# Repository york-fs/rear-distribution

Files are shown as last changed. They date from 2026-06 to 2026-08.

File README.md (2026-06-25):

# Rear Distribution Board







The rear distribution board is the central board of the LVS. It provides fusing for all other LVS components and
interfaces with the front, TSAC, and TS box distribution boards, as well as the inverter via AMPSEAL connections.

[Latest Release](https://github.com/york-fs/rear-distribution/releases/latest)
[Interactive BOM](https://york-fs.github.io/rear-distribution/ibom.html)

## Features

* **Blade Fuse Holders for All Other LVS components**
* **Fused 12 V and Shutdown Monitoring**
* **On-board microSD Slot**
* **UART Output for Radio Communication**

Render Preview

## Cloning

A recursive clone must be used to download the `kicad-library` repository:

    git clone --recursive https://github.com/york-fs/rear-distribution.git

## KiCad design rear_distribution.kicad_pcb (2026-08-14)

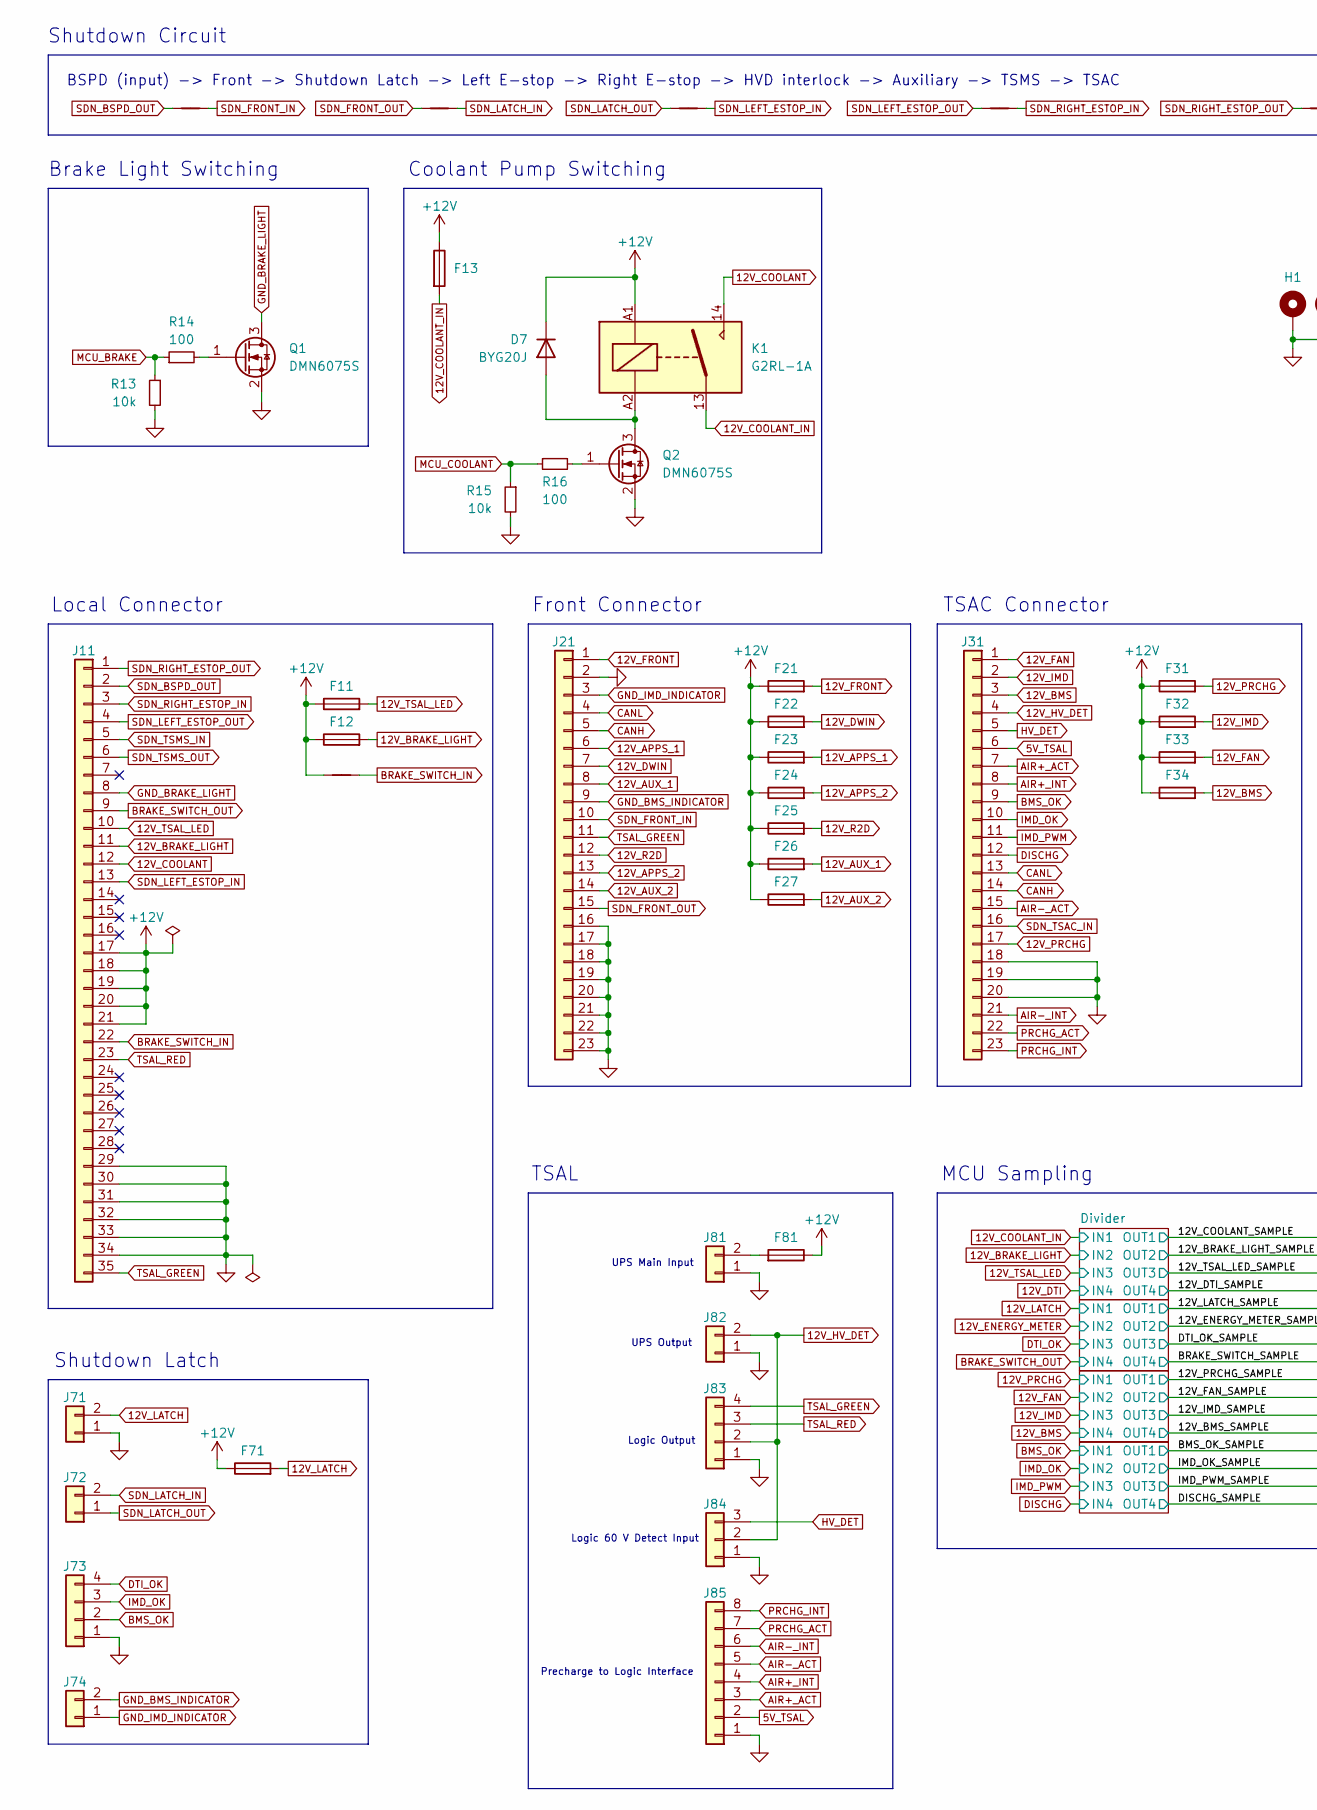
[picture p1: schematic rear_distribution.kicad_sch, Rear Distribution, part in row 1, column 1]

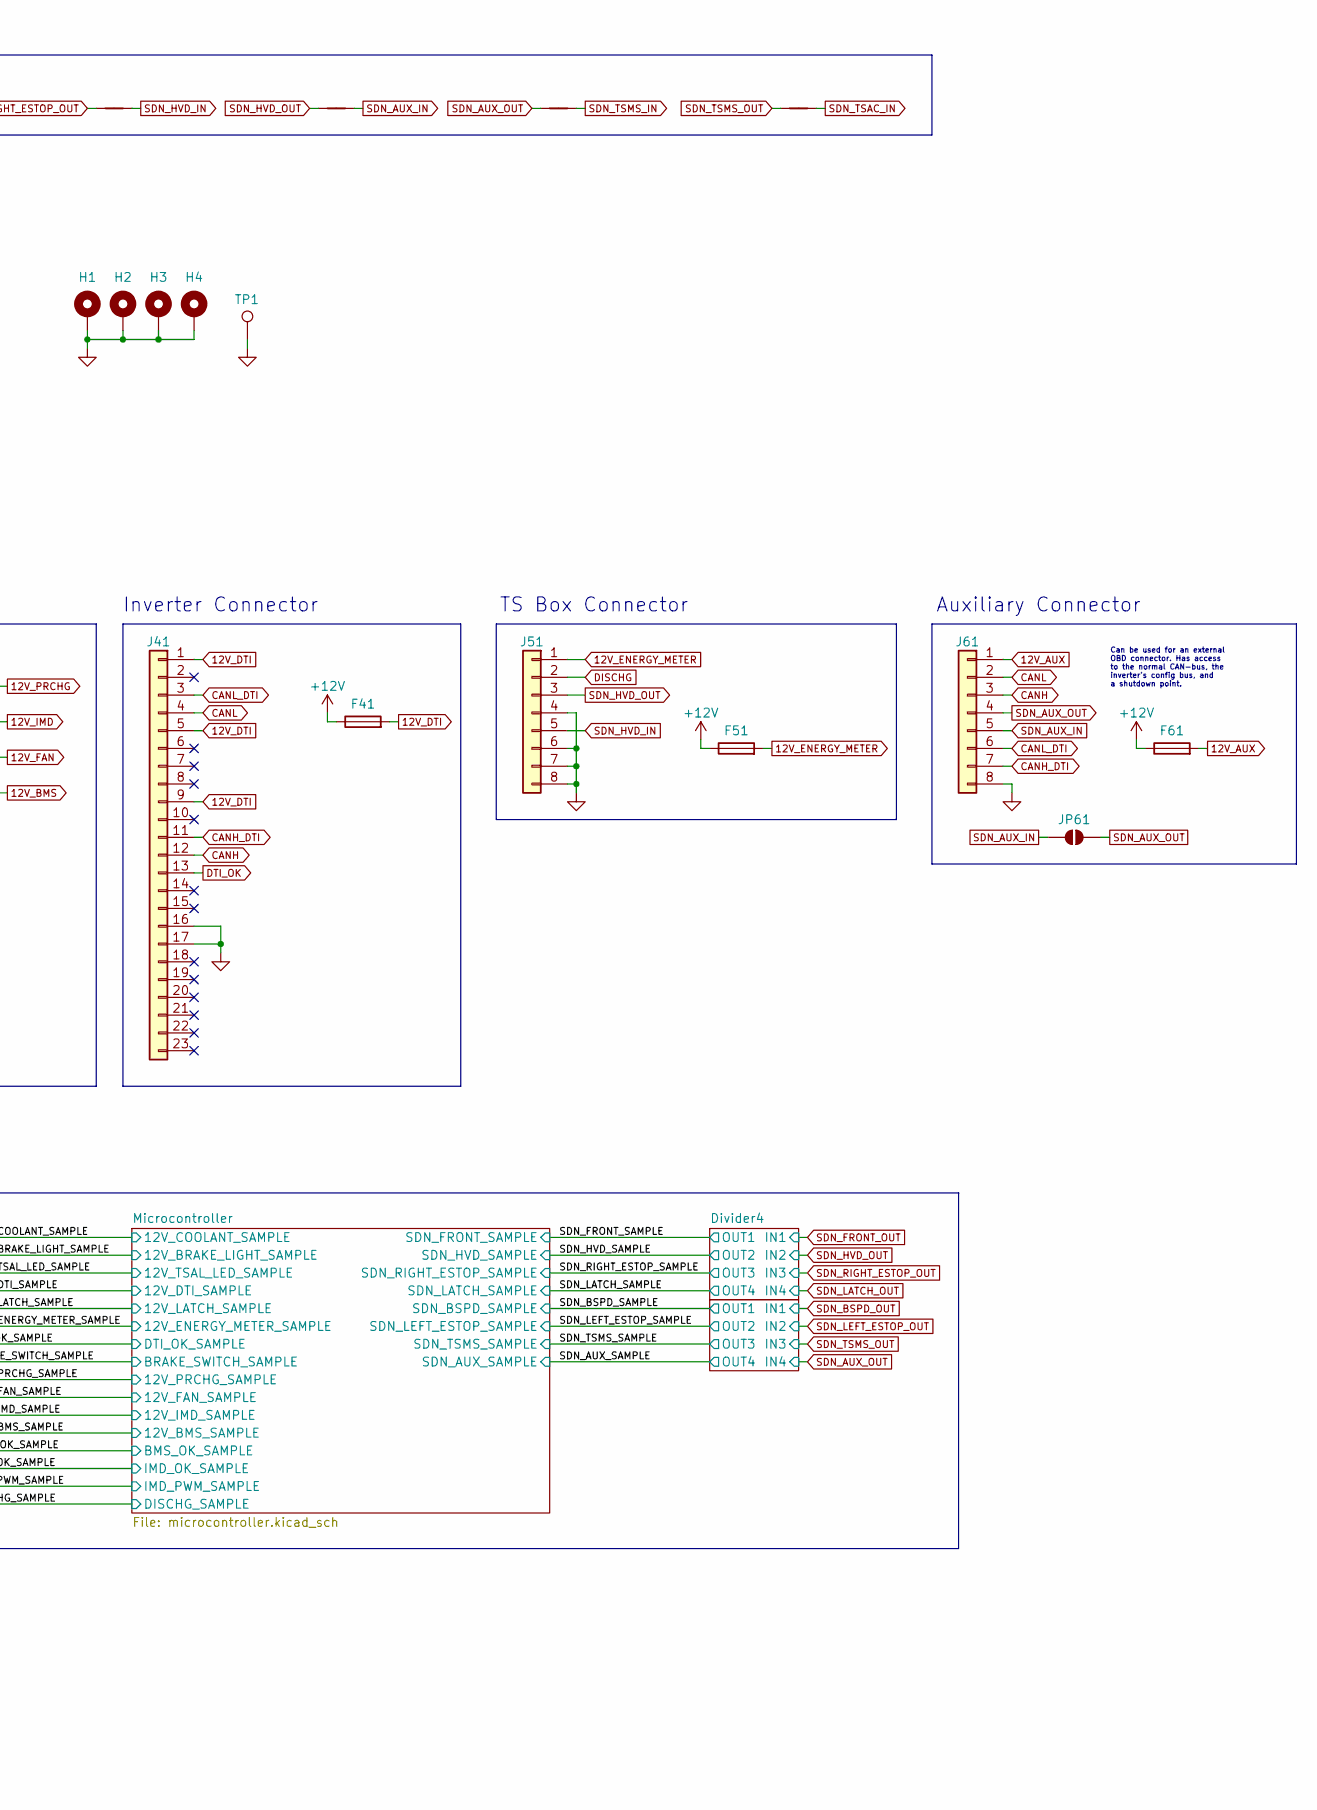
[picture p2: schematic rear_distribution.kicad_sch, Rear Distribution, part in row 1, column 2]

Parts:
D7: BYG20J; D_SMA; Mfr # BYG20J-E3/TR; DigiKey # BYG20J-E3/TR3GICT-ND
F11, F12, F13, F21, F22, F23, F24, F25, F26, F27, F31, F32, F33, F34, F41, F51, F61, F71, F81: Fuse; Keystone_3557-2; Mfr # 3557-2; DigiKey # 36-3557-2-ND
H1, H2, H3, H4: MountingHole_Pad; MountingHole_3.2mm_M3_Pad_Via
J11: Conn_01x35; AMPSEAL-35-776163; Mfr # 776163-1; DigiKey # A106460-ND
J21, J31, J41: Conn_01x23; AMPSEAL-23-776087; Mfr # 776087-1; DigiKey # A107007-ND
J51, J61: Conn_01x08; AMPSEAL-8-776280; Mfr # 776280-1; DigiKey # 776280-1-ND
J71, J81: Conn_01x02; MolexMicrofitPlus1x2; Mfr # 2157601022; DigiKey # 900-2157601022-ND
J72: Conn_01x02; MolexMicrofitPlus1x2; Mfr # 2157601032; DigiKey # 900-2157601032-ND
J73, J83: Conn_01x04; MolexMicrofitPlus1x4; Mfr # 2157601004; DigiKey # 900-2157601004-ND
J74, J82: Conn_01x02; MolexMicrofitPlus1x2; Mfr # 2157601002; DigiKey # 900-2157601002-ND
J84: Conn_01x03; MolexMicrofitPlus1x3; Mfr # 2157601003; DigiKey # 900-2157601003-ND
J85: Conn_01x08; MolexMicrofitPlus1x8; Mfr # 2157601008; DigiKey # 900-2157601008-ND
JP61: SolderJumper_2_Open; SolderJumper-2_P1.3mm_Open_RoundedPad1.0x1.5mm
K1: G2RL-1A; Relay_SPST_Omron_G2RL-1A; Mfr # G2RL-1A-DC12; DigiKey # Z140-ND
NT2, NT3, NT4, NT5, NT6, NT7, NT8, NT9, NT10: NetTie_2; NetTie-2_SMD_Pad0.5mm
Q1, Q2: DMN6075S; SOT-23; Mfr # DMN6075S-7; DigiKey # DMN6075S-7DICT-ND
R13, R15: 10k; R_0603_1608Metric; Mfr # 0603WAF1002T5E; LCSC # C25804
R14, R16: 100; R_0603_1608Metric
TP1: TestPoint; TestPoint_Keystone_5019_Miniature; Mouser # 534-5019; DigiKey # 36-5019CT-ND

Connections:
5V_TSAL: J31.6, J85.2
12V_APPS_1: F23.2, J21.6
12V_APPS_2: F24.2, J21.13
12V_AUX: F61.2, J61.1
12V_AUX_1: F26.2, J21.8
12V_AUX_2: F27.2, J21.14
12V_BMS: F34.2, J31.3; also elsewhere on the board
12V_BRAKE_LIGHT: F12.2, J11.11; also elsewhere on the board
12V_COOLANT: J11.12, K1.14
12V_COOLANT_IN: F13.2, K1.13; also elsewhere on the board
12V_DTI: F41.2, J41.1, J41.5, J41.9; also elsewhere on the board
12V_DWIN: F22.2, J21.7
12V_ENERGY_METER: F51.2, J51.1; also elsewhere on the board
12V_FAN: F33.2, J31.1; also elsewhere on the board
12V_FRONT: F21.2, J21.1
12V_HV_DET: J31.4, J82.2, J83.2, J84.2
12V_IMD: F32.2, J31.2; also elsewhere on the board
12V_LATCH: F71.2, J71.2; also elsewhere on the board
12V_PRCHG: F31.2, J31.17; also elsewhere on the board
12V_R2D: F25.2, J21.12
12V_TSAL_LED: F11.2, J11.10; also elsewhere on the board
+12V: D7.1 (K), F11.1, F12.1, F13.1, F21.1, F22.1, F23.1, F24.1, F25.1, F26.1, F27.1, F31.1, F32.1, F33.1, F34.1, F41.1, F51.1, F61.1, F71.1, F81.1, J11.17, J11.18, J11.19, J11.20, J11.21, K1.A1, NT2.1; also elsewhere on the board
AIR+_ACT: J31.7, J85.3
AIR+_INT: J31.8, J85.4
AIR-_ACT: J31.15, J85.5
AIR-_INT: J31.21, J85.6
BMS_OK: J31.9, J73.2; also elsewhere on the board
BRAKE_SWITCH_IN: J11.22, NT2.2
BRAKE_SWITCH_OUT: J11.9; also elsewhere on the board
CANH: J21.5, J31.14, J41.12, J61.3; also elsewhere on the board
CANH_DTI: J41.11, J61.7
CANL: J21.4, J31.13, J41.4, J61.2; also elsewhere on the board
CANL_DTI: J41.3, J61.6
DISCHG: J31.12, J51.2; also elsewhere on the board
DTI_OK: J41.13, J73.4; also elsewhere on the board
GND: H1.1, H2.1, H3.1, H4.1, J11.29, J11.30, J11.31, J11.32, J11.33, J11.34, J21.2, J21.16, J21.17, J21.18, J21.19, J21.20, J21.21, J21.22, J21.23, J31.18, J31.19, J31.20, J41.16, J41.17, J51.4, J51.6, J51.7, J51.8, J61.8, J71.1, J73.1, J81.1, J82.1, J83.1, J84.1, J85.1, Q1.2 (S), Q2.2 (S), R13.2, R15.2, TP1.1; also elsewhere on the board
GND_BMS_INDICATOR: J21.9, J74.2
GND_BRAKE_LIGHT: J11.8, Q1.3 (D)
GND_IMD_INDICATOR: J21.3, J74.1
HV_DET: J31.5, J84.3
IMD_OK: J31.10, J73.3; also elsewhere on the board
IMD_PWM: J31.11; also elsewhere on the board
MCU_BRAKE: R13.1, R14.1; also elsewhere on the board
MCU_COOLANT: R15.1, R16.1; also elsewhere on the board
unnamed: D7.2 (A), K1.A2, Q2.3 (D)
unnamed: F81.2, J81.2
unnamed: Q1.1 (G), R14.2
unnamed: Q2.1 (G), R16.2
PRCHG_ACT: J31.22, J85.7
PRCHG_INT: J31.23, J85.8
SDN_AUX_IN: J61.5, JP61.1 (A), NT8.2
SDN_AUX_OUT: J61.4, JP61.2 (B), NT9.1; also elsewhere on the board
SDN_BSPD_OUT: J11.2, NT3.1; also elsewhere on the board
SDN_FRONT_IN: J21.10, NT3.2
SDN_FRONT_OUT: J21.15, NT4.1; also elsewhere on the board
SDN_HVD_IN: J51.5, NT7.2
SDN_HVD_OUT: J51.3, NT8.1; also elsewhere on the board
SDN_LATCH_IN: J72.2, NT4.2
SDN_LATCH_OUT: J72.1, NT5.1; also elsewhere on the board
SDN_LEFT_ESTOP_IN: J11.13, NT5.2
SDN_LEFT_ESTOP_OUT: J11.4, NT6.1; also elsewhere on the board
SDN_RIGHT_ESTOP_IN: J11.3, NT6.2
SDN_RIGHT_ESTOP_OUT: J11.1, NT7.1; also elsewhere on the board
SDN_TSAC_IN: J31.16, NT10.2
SDN_TSMS_IN: J11.5, NT9.2
SDN_TSMS_OUT: J11.6, NT10.1; also elsewhere on the board
TSAL_GREEN: J11.35, J21.11, J83.4
TSAL_RED: J11.23, J83.3

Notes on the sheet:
TSAL
Logic Output
UPS Main Input
Inverter Connector
UPS Output
Logic 60 V Detect Input
Auxiliary Connector
TSAC Connector
Local Connector
Precharge to Logic Interface
MCU Sampling
Can be used for an external OBD connector. Has access to the normal CAN-bus, the inverter's config bus, and a shutdown point.
Front Connector
BSPD (input) -> Front -> Shutdown Latch -> Left E-stop -> Right E-stop -> HVD interlock -> Auxiliary -> TSMS -> TSAC
Brake Light Switching
Shutdown Latch
Shutdown Circuit
Coolant Pump Switching
TS Box Connector

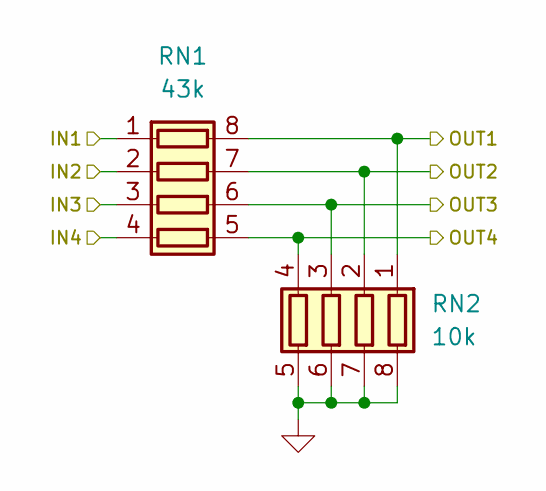
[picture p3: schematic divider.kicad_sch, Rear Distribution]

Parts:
RN1: 43k; R_Array_Convex_4x1206; Mfr # YC324-JK-0747KL; DigiKey # 13-YC324-JK-0747KLCT-ND
RN2: 10k; R_Array_Convex_4x1206; Mfr # YC324-FK-0710KL; DigiKey # 13-YC324-FK-0710KLCT-ND

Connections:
12V_BRAKE_LIGHT: RN1.2 (R2.1); also elsewhere on the board
12V_COOLANT_IN: RN1.1 (R1.1); also elsewhere on the board
12V_DTI: RN1.4 (R4.1); also elsewhere on the board
12V_TSAL_LED: RN1.3 (R3.1); also elsewhere on the board
/12V_BRAKE_LIGHT_SAMPLE: RN1.7 (R2.2), RN2.2 (R2.1); also elsewhere on the board
/12V_COOLANT_SAMPLE: RN1.8 (R1.2), RN2.1 (R1.1); also elsewhere on the board
/12V_DTI_SAMPLE: RN1.5 (R4.2), RN2.4 (R4.1); also elsewhere on the board
/12V_TSAL_LED_SAMPLE: RN1.6 (R3.2), RN2.3 (R3.1); also elsewhere on the board
GND: RN2.5 (R4.2), RN2.6 (R3.2), RN2.7 (R2.2), RN2.8 (R1.2); also elsewhere on the board

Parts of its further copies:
RN3, RN5, RN7, RN9, RN11: 43k; R_Array_Convex_4x1206; Mfr # YC324-JK-0747KL; DigiKey # 13-YC324-JK-0747KLCT-ND
RN4, RN6, RN8, RN10, RN12: 10k; R_Array_Convex_4x1206; Mfr # YC324-FK-0710KL; DigiKey # 13-YC324-FK-0710KLCT-ND

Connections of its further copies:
12V_BMS: RN5.4 (R4.1); also elsewhere on the board
12V_ENERGY_METER: RN3.2 (R2.1); also elsewhere on the board
12V_FAN: RN5.2 (R2.1); also elsewhere on the board
12V_IMD: RN5.3 (R3.1); also elsewhere on the board
12V_LATCH: RN3.1 (R1.1); also elsewhere on the board
12V_PRCHG: RN5.1 (R1.1); also elsewhere on the board
/12V_BMS_SAMPLE: RN5.5 (R4.2), RN6.4 (R4.1); also elsewhere on the board
/12V_ENERGY_METER_SAMPLE: RN3.7 (R2.2), RN4.2 (R2.1); also elsewhere on the board
/12V_FAN_SAMPLE: RN5.7 (R2.2), RN6.2 (R2.1); also elsewhere on the board
/12V_IMD_SAMPLE: RN5.6 (R3.2), RN6.3 (R3.1); also elsewhere on the board
/12V_LATCH_SAMPLE: RN3.8 (R1.2), RN4.1 (R1.1); also elsewhere on the board
/12V_PRCHG_SAMPLE: RN5.8 (R1.2), RN6.1 (R1.1); also elsewhere on the board
/BMS_OK_SAMPLE: RN7.8 (R1.2), RN8.1 (R1.1); also elsewhere on the board
/BRAKE_SWITCH_SAMPLE: RN3.5 (R4.2), RN4.4 (R4.1); also elsewhere on the board
/DISCHG_SAMPLE: RN7.5 (R4.2), RN8.4 (R4.1); also elsewhere on the board
/DTI_OK_SAMPLE: RN3.6 (R3.2), RN4.3 (R3.1); also elsewhere on the board
/IMD_OK_SAMPLE: RN7.7 (R2.2), RN8.2 (R2.1); also elsewhere on the board
/IMD_PWM_SAMPLE: RN7.6 (R3.2), RN8.3 (R3.1); also elsewhere on the board
/SDN_AUX_SAMPLE: RN11.5 (R4.2), RN12.4 (R4.1); also elsewhere on the board
/SDN_BSPD_SAMPLE: RN11.8 (R1.2), RN12.1 (R1.1); also elsewhere on the board
/SDN_FRONT_SAMPLE: RN9.8 (R1.2), RN10.1 (R1.1); also elsewhere on the board
/SDN_HVD_SAMPLE: RN9.7 (R2.2), RN10.2 (R2.1); also elsewhere on the board
/SDN_LATCH_SAMPLE: RN9.5 (R4.2), RN10.4 (R4.1); also elsewhere on the board
/SDN_LEFT_ESTOP_SAMPLE: RN11.7 (R2.2), RN12.2 (R2.1); also elsewhere on the board
/SDN_RIGHT_ESTOP_SAMPLE: RN9.6 (R3.2), RN10.3 (R3.1); also elsewhere on the board
/SDN_TSMS_SAMPLE: RN11.6 (R3.2), RN12.3 (R3.1); also elsewhere on the board
BMS_OK: RN7.1 (R1.1); also elsewhere on the board
BRAKE_SWITCH_OUT: RN3.4 (R4.1); also elsewhere on the board
DISCHG: RN7.4 (R4.1); also elsewhere on the board
DTI_OK: RN3.3 (R3.1); also elsewhere on the board
GND: RN4.5 (R4.2), RN4.6 (R3.2), RN4.7 (R2.2), RN4.8 (R1.2), RN6.5 (R4.2), RN6.6 (R3.2), RN6.7 (R2.2), RN6.8 (R1.2), RN8.5 (R4.2), RN8.6 (R3.2), RN8.7 (R2.2), RN8.8 (R1.2), RN10.5 (R4.2), RN10.6 (R3.2), RN10.7 (R2.2), RN10.8 (R1.2), RN12.5 (R4.2), RN12.6 (R3.2), RN12.7 (R2.2), RN12.8 (R1.2); also elsewhere on the board
IMD_OK: RN7.2 (R2.1); also elsewhere on the board
IMD_PWM: RN7.3 (R3.1); also elsewhere on the board
SDN_AUX_OUT: RN11.4 (R4.1); also elsewhere on the board
SDN_BSPD_OUT: RN11.1 (R1.1); also elsewhere on the board
SDN_FRONT_OUT: RN9.1 (R1.1); also elsewhere on the board
SDN_HVD_OUT: RN9.2 (R2.1); also elsewhere on the board
SDN_LATCH_OUT: RN9.4 (R4.1); also elsewhere on the board
SDN_LEFT_ESTOP_OUT: RN11.2 (R2.1); also elsewhere on the board
SDN_RIGHT_ESTOP_OUT: RN9.3 (R3.1); also elsewhere on the board
SDN_TSMS_OUT: RN11.3 (R3.1); also elsewhere on the board

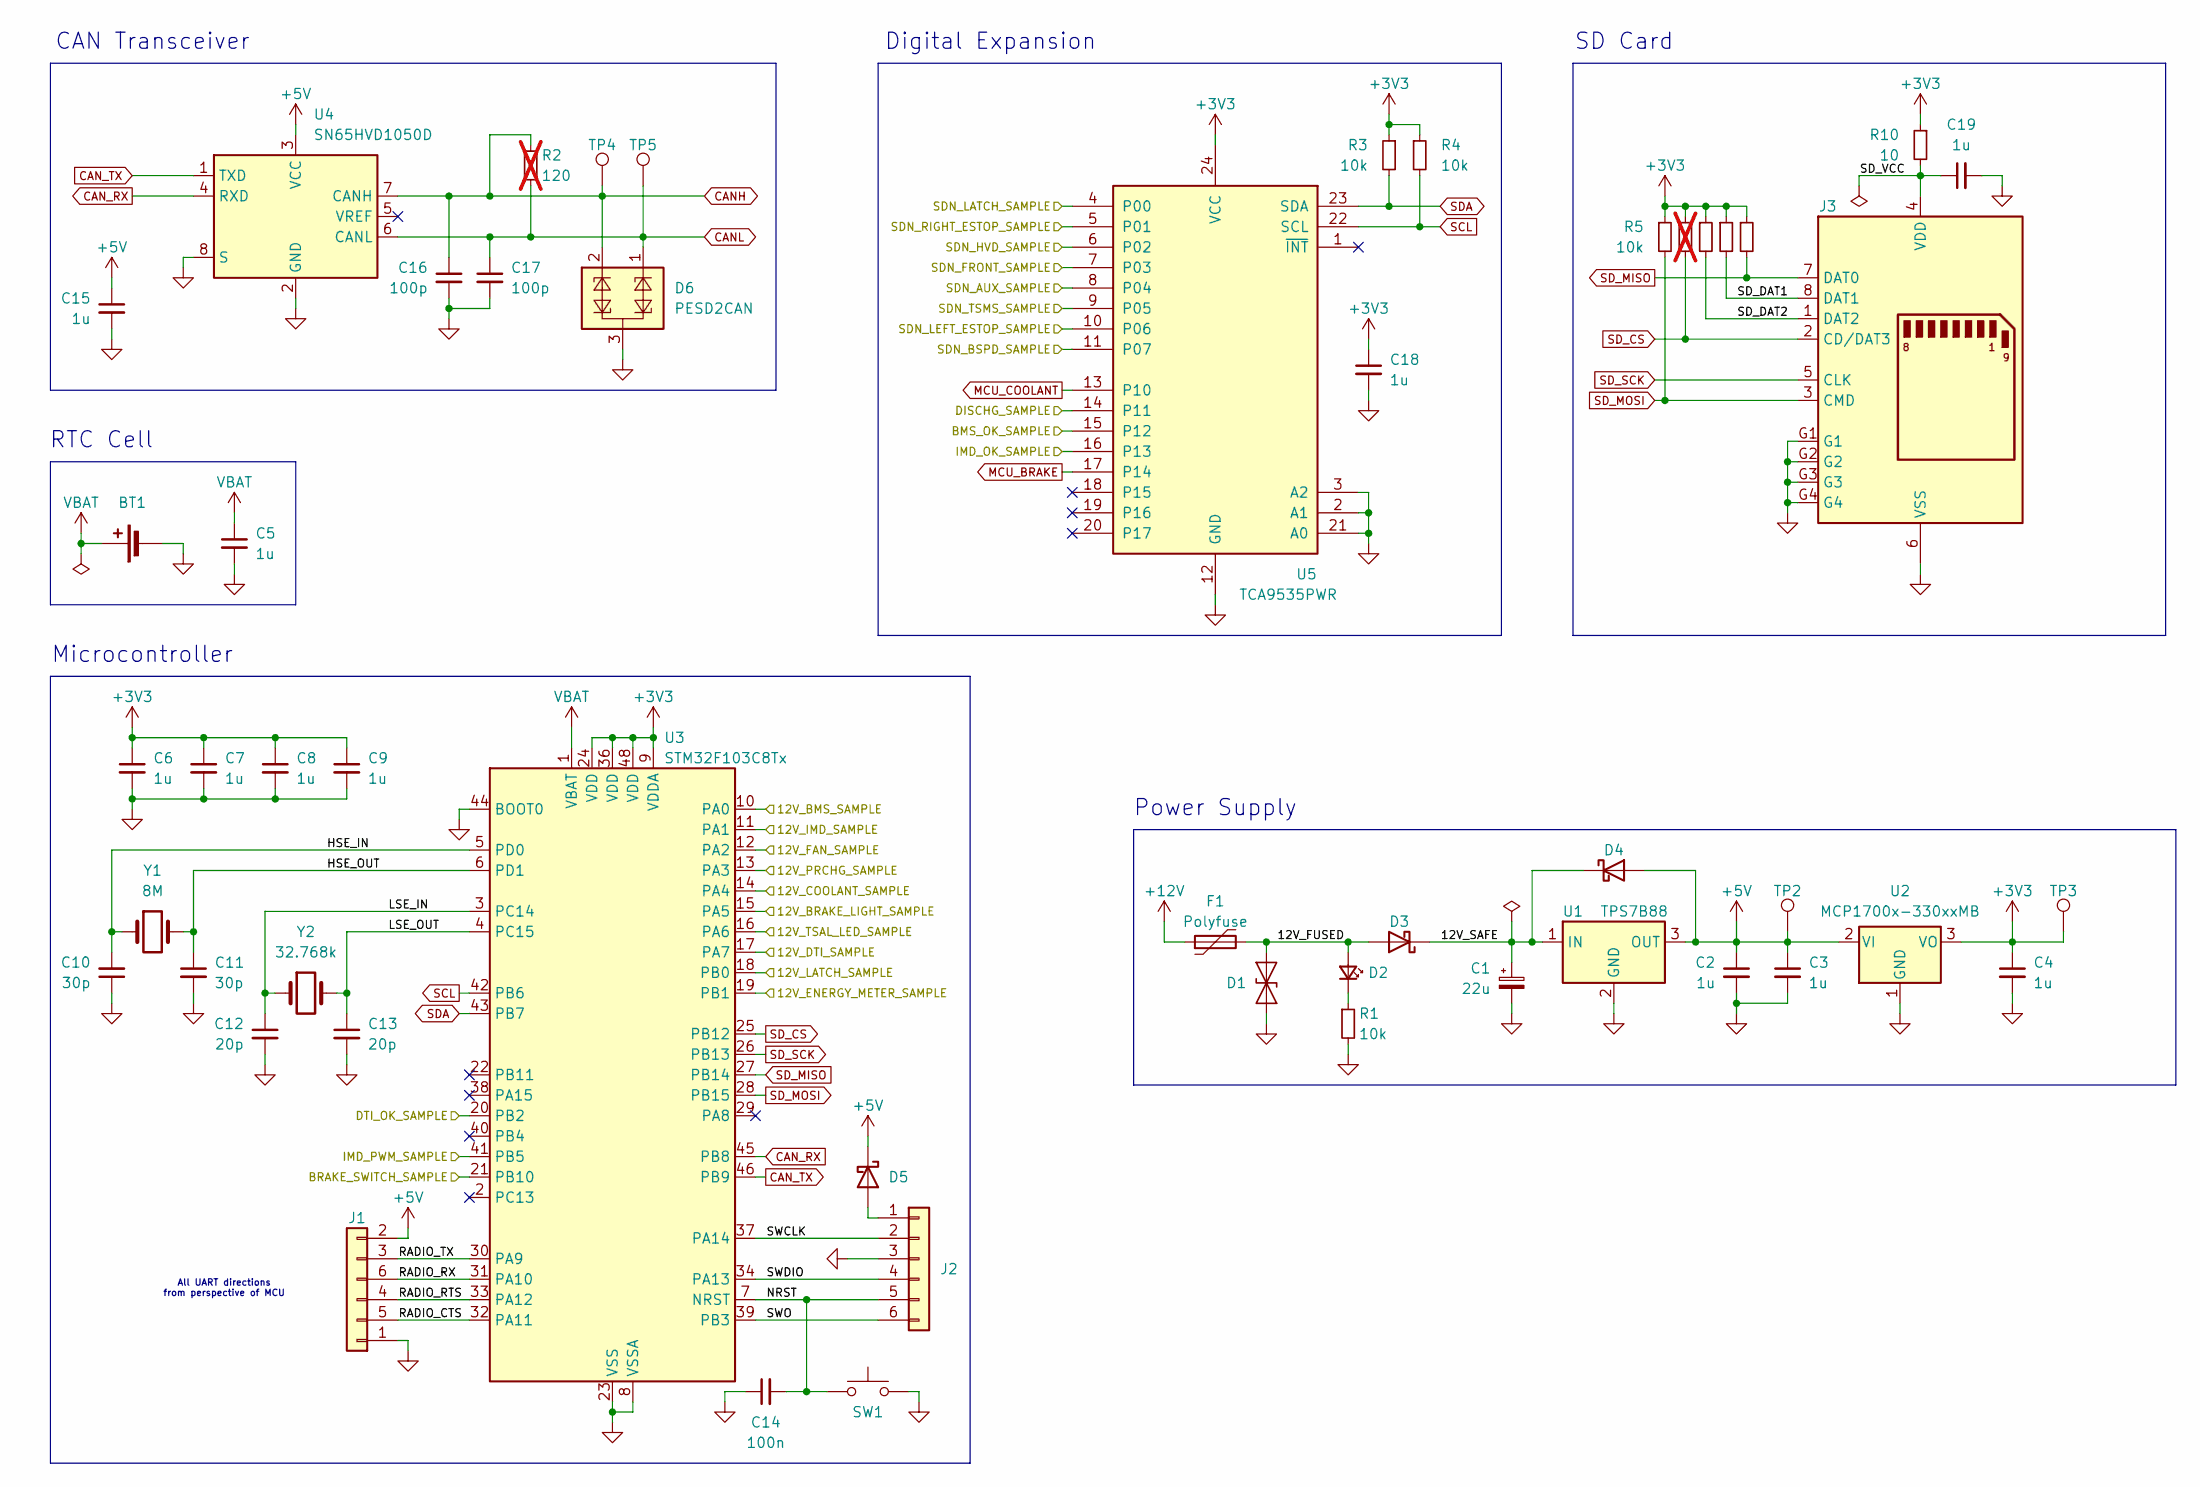
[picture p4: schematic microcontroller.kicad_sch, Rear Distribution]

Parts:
BT1: Battery_Cell; BAT-SMD_BS-CR2032-8
C1: 22u; CP_Elec_6.3x7.7; Mfr # EEEFK1J220XP; DigiKey # PCE3821CT-ND
C2, C3, C4, C5, C6, C7, C8, C9, C15, C18, C19: 1u; C_0603_1608Metric; Mfr # CL10B105KB8NQNC; LCSC # C5199872
C10, C11: 30p; C_0603_1608Metric; Mfr # GQM1875C2E300GB12D; DigiKey # 490-GQM1875C2E300GB12DCT-ND
C12, C13: 20p; C_0603_1608Metric
C14: 100n; C_0603_1608Metric; Mfr # CL10B104KB8NNNC; DigiKey # 1276-1000-1-ND
C16, C17: 100p; C_0603_1608Metric; Mfr # GCM1885C2A101JA16D; DigiKey # 490-4771-1-ND
D1: SMAJ24CA; D_SMA; Mfr # SMAJ24CA; DigiKey # SMAJ24CALFCT-ND
D2: LED_Small; LED_0603_1608Metric; Mfr # NCD0603R1; LCSC # C84263
D3, D4, D5: D_Schottky; D_SOD-323; Mfr # NSR0530H; DigiKey # NSR0530HT1GOSCT-ND
D6: PESD2CAN; SOT-23; Mfr # PESD2CAN,215; DigiKey # 1727-3891-1-ND
F1: Polyfuse; C_0805_2012Metric; Mfr # 0805L010/24YR; DigiKey # F11311CT-ND
J1: Conn_01x06; MolexMicrofitPlus2x3; Mfr # 2125280600; DigiKey # 900-2125280600-ND
J2: Conn_01x06; IDC-Connector-2x3; Mfr # HX JN1.27-2x3P ZZ H4.9; LCSC # C42372545
J3: 47219-2001; Molex_SD_Slot_47219-2001; Mfr # 472192001; DigiKey # WM6698CT-ND
R1, R3, R4, R5, R7, R8, R9: 10k; R_0603_1608Metric; Mfr # 0603WAF1002T5E; LCSC # C25804
R2: 120; R_0603_1608Metric; not fitted
R6: 10k; R_0603_1608Metric; Mfr # 0603WAF1002T5E; LCSC # C25804; not fitted
R10: 10; R_0603_1608Metric
SW1: SW_Push; SW_Push_1P1T_NO_Vertical_Wuerth_434133025816; Mfr # SKRPACE010; DigiKey # 4809-SKRPACE010CT-ND
TP2, TP3: TestPoint; TestPoint_Keystone_5000-5004_Miniature; Mouser # 534-5000; DigiKey # 36-5000-ND
TP4, TP5: TestPoint; TestPoint_THTPad_D2.0mm_Drill1.0mm
U1: TPS7B88; TO-252-2; Mfr # TPS7B8850QKVURQ1; DigiKey # 296-TPS7B8850QKVURQ1CT-ND
U2: MCP1700x-330xxMB; SOT-89-3; Mfr # MCP1700T-3302E/MB; DigiKey # MCP1700T3302EMBCT-ND
U3: STM32F103C8Tx; LQFP-48_7x7mm_P0.5mm; Mfr # STM32F103C8T6; DigiKey # 497-17666-1-ND
U4: SN65HVD1050D; SOIC-8_3.9x4.9mm_P1.27mm; Mfr # SN65HVD1050DR; DigiKey # 296-26335-1-ND
U5: TCA9535PWR; TSSOP-24_4.4x7.8mm_P0.65mm; Mfr # TCA9535PWR; DigiKey # 296-25129-1-ND
Y1: 8M; Crystal_SMD_5032-2Pin_5.0x3.2mm; Mfr # X50328MSB2GI; LCSC # C115962
Y2: 32.768k; Crystal_SMD_G8-2Pin_3.2x1.5mm

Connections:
+3V3: C4.1, C6.1, C7.1, C8.1, C9.1, C18.1, R3.1, R4.1, R5.1, R6.1, R7.1, R8.1, R9.1, R10.1, TP3.1, U2.3 (VO), U3.9 (VDDA), U3.24 (VDD), U3.36 (VDD), U3.48 (VDD), U5.24 (VCC)
+5V: C2.1, C3.1, C15.1, D4.2 (A), D5.1 (K), J1.2, TP2.1, U1.3 (OUT), U2.2 (VI), U4.3 (VCC)
+12V: F1.1; also elsewhere on the board
/12V_BMS_SAMPLE: U3.10 (PA0); also elsewhere on the board
/12V_BRAKE_LIGHT_SAMPLE: U3.15 (PA5); also elsewhere on the board
/12V_COOLANT_SAMPLE: U3.14 (PA4); also elsewhere on the board
/12V_DTI_SAMPLE: U3.17 (PA7); also elsewhere on the board
/12V_ENERGY_METER_SAMPLE: U3.19 (PB1); also elsewhere on the board
/12V_FAN_SAMPLE: U3.12 (PA2); also elsewhere on the board
/12V_IMD_SAMPLE: U3.11 (PA1); also elsewhere on the board
/12V_LATCH_SAMPLE: U3.18 (PB0); also elsewhere on the board
/12V_PRCHG_SAMPLE: U3.13 (PA3); also elsewhere on the board
/12V_TSAL_LED_SAMPLE: U3.16 (PA6); also elsewhere on the board
/BMS_OK_SAMPLE: U5.15 (P12); also elsewhere on the board
/BRAKE_SWITCH_SAMPLE: U3.21 (PB10); also elsewhere on the board
/DISCHG_SAMPLE: U5.14 (P11); also elsewhere on the board
/DTI_OK_SAMPLE: U3.20 (PB2); also elsewhere on the board
/IMD_OK_SAMPLE: U5.16 (P13); also elsewhere on the board
/IMD_PWM_SAMPLE: U3.41 (PB5); also elsewhere on the board
/Microcontroller/12V_FUSED: D1.2 (A2), D2.2 (A), D3.2 (A), F1.2
/Microcontroller/12V_SAFE: C1.1, D3.1 (K), D4.1 (K), U1.1 (IN)
/Microcontroller/HSE_IN: C10.2, U3.5 (PD0), Y1.1
/Microcontroller/HSE_OUT: C11.1, U3.6 (PD1), Y1.2
/Microcontroller/LSE_IN: C12.1, U3.3 (PC14), Y2.1
/Microcontroller/LSE_OUT: C13.1, U3.4 (PC15), Y2.2
/Microcontroller/NRST: C14.2, J2.5, SW1.1, U3.7 (NRST)
/Microcontroller/RADIO_CTS: J1.5, U3.32 (PA11)
/Microcontroller/RADIO_RTS: J1.4, U3.33 (PA12)
/Microcontroller/RADIO_RX: J1.6, U3.31 (PA10)
/Microcontroller/RADIO_TX: J1.3, U3.30 (PA9)
/Microcontroller/SD_DAT1: J3.8 (DAT1), R8.2
/Microcontroller/SD_DAT2: J3.1 (DAT2), R7.2
/Microcontroller/SD_VCC: C19.1, J3.4 (VDD), R10.2
/Microcontroller/SWCLK: J2.2, U3.37 (PA14)
/Microcontroller/SWDIO: J2.4, U3.34 (PA13)
/Microcontroller/SWO: J2.6, U3.39 (PB3)
/SDN_AUX_SAMPLE: U5.8 (P04); also elsewhere on the board
/SDN_BSPD_SAMPLE: U5.11 (P07); also elsewhere on the board
/SDN_FRONT_SAMPLE: U5.7 (P03); also elsewhere on the board
/SDN_HVD_SAMPLE: U5.6 (P02); also elsewhere on the board
/SDN_LATCH_SAMPLE: U5.4 (P00); also elsewhere on the board
/SDN_LEFT_ESTOP_SAMPLE: U5.10 (P06); also elsewhere on the board
/SDN_RIGHT_ESTOP_SAMPLE: U5.5 (P01); also elsewhere on the board
/SDN_TSMS_SAMPLE: U5.9 (P05); also elsewhere on the board
CANH: C16.1, D6.2 (C2), R2.1, TP4.1, U4.7 (CANH); also elsewhere on the board
CANL: C17.1, D6.1 (C1), R2.2, TP5.1, U4.6 (CANL); also elsewhere on the board
CAN_RX: U3.45 (PB8), U4.4 (RXD)
CAN_TX: U3.46 (PB9), U4.1 (TXD)
GND: BT1.2 (-), C1.2, C2.2, C3.2, C4.2, C5.2, C6.2, C7.2, C8.2, C9.2, C10.1, C11.2, C12.2, C13.2, C14.1, C15.2, C16.2, C17.2, C18.2, C19.2, D1.1 (A1), D6.3 (CC), J1.1, J2.3, J3.6 (VSS), J3.G1, J3.G2, J3.G3, J3.G4, R1.2, SW1.2, U1.2 (GND), U2.1 (GND), U3.8 (VSSA), U3.23 (VSS), U3.35 (VSS), U3.44 (BOOT0), U3.47 (VSS), U4.2 (GND), U4.8 (S), U5.2 (A1), U5.3 (A2), U5.12 (GND), U5.21 (A0); also elsewhere on the board
MCU_BRAKE: U5.17 (P14); also elsewhere on the board
MCU_COOLANT: U5.13 (P10); also elsewhere on the board
unnamed: D2.1 (K), R1.1
unnamed: D5.2 (A), J2.1
SCL: R4.2, U3.42 (PB6), U5.22 (SCL)
SDA: R3.2, U3.43 (PB7), U5.23 (SDA)
SD_CS: J3.2 (CD/DAT3), R6.2, U3.25 (PB12)
SD_MISO: J3.7 (DAT0), R9.2, U3.27 (PB14)
SD_MOSI: J3.3 (CMD), R5.2, U3.28 (PB15)
SD_SCK: J3.5 (CLK), U3.26 (PB13)
VBAT: BT1.1 (+), C5.1, U3.1 (VBAT)

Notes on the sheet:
Microcontroller
RTC Cell
SD Card
Digital Expansion
CAN Transceiver
Power Supply
All UART directions from perspective of MCU

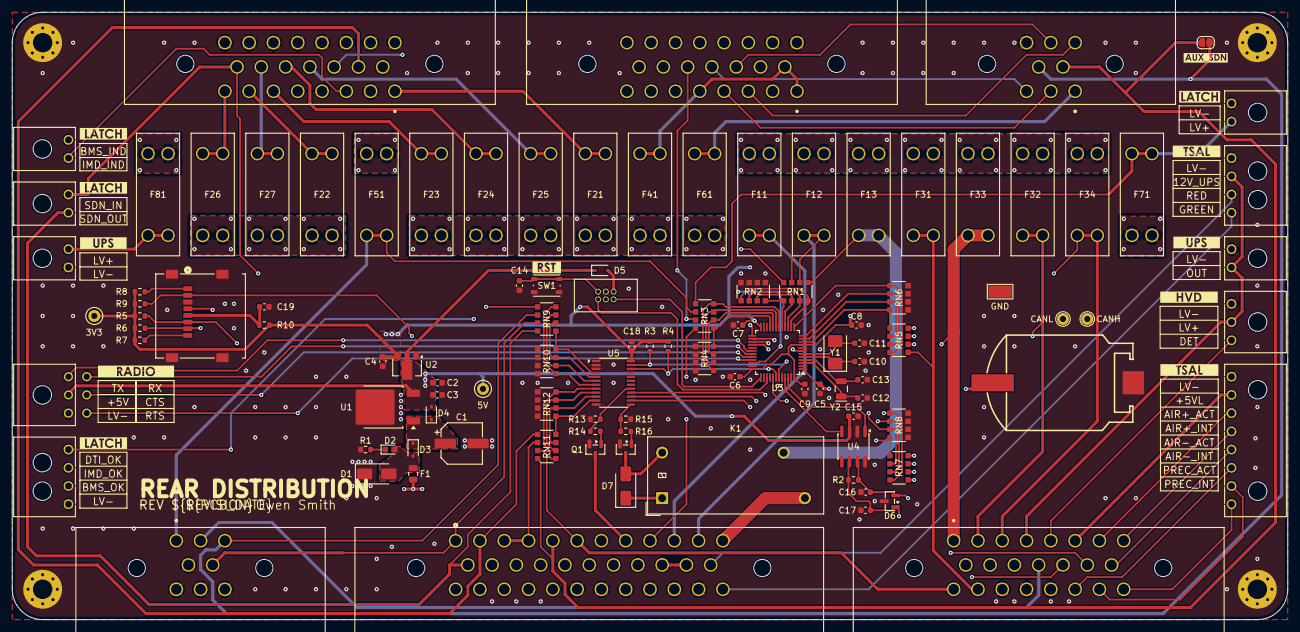
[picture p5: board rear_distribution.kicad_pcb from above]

Board: 4 copper layers, 210.0 x 100.0 mm, 133 parts (1 on the bottom side), 122 nets.

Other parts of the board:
kibuzzard-6A35CDBD: G***; kibuzzard-6A35CDBD
kibuzzard-6A35CEAD: G***; kibuzzard-6A35CEAD
kibuzzard-6A35CF3E, kibuzzard-6A35CF3E#2: G***; kibuzzard-6A35CF3E
kibuzzard-6A35CF98: G***; kibuzzard-6A35CF98
kibuzzard-6A3571FC: G***; kibuzzard-6A3571FC
kibuzzard-6A3572FA: G***; kibuzzard-6A3572FA
kibuzzard-6A3574B6: G***; kibuzzard-6A3574B6
kibuzzard-6A35710C: G***; kibuzzard-6A35710C
kibuzzard-6A35750C: G***; kibuzzard-6A35750C
kibuzzard-6910BB45: G***; kibuzzard-6910BB45
kibuzzard-6940937D: G***; kibuzzard-6940937D

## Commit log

2026-06-16 schematic: Tentatively finish major schematic parts
    [divider.kicad_sch, microcontroller.kicad_sch, rear_distribution.kicad_sch]
2026-06-16 schematic: Re-annotate and add RTC battery
    [divider.kicad_sch, microcontroller.kicad_sch, rear_distribution.kicad_sch]
2026-06-16 schematic: Assign footprints and fill most of BOM
    [divider.kicad_sch, microcontroller.kicad_sch, rear_distribution.kicad_sch]
2026-06-16 *: Setup PCB
    [microcontroller.kicad_sch, rear_distribution.kicad_pcb, rear_distribution.kicad_sch]
2026-06-18 pcb: Add layout progress so far
    [microcontroller.kicad_sch, rear_distribution.kicad_pcb, rear_distribution.kicad_sch]
2026-06-19 *: Tentatively finish everything
    [microcontroller.kicad_sch, rear_distribution.kicad_pcb, rear_distribution.kicad_sch]
2026-06-19 pcb: Move RN6 designator
    [rear_distribution.kicad_pcb]
2026-06-19 pcb: Add model for 2x3 MF+ and fix fuse model alignment
    [microcontroller.kicad_sch, rear_distribution.kicad_pcb]
2026-06-19 *: Add CAN test points
    [microcontroller.kicad_sch, rear_distribution.kicad_pcb, rear_distribution.kicad_sch]
2026-06-19 pcb: Cleanup silkscreen some more
    [rear_distribution.kicad_pcb]
2026-06-22 pcb: Setup AISLER push
    [rear_distribution.kicad_pcb]
2026-06-25 schematic: Cleanup BOM
    [divider.kicad_sch, microcontroller.kicad_sch, rear_distribution.kicad_pcb]
2026-06-25 schematic: Cleanup root schematic page
    [microcontroller.kicad_sch, rear_distribution.kicad_sch]
2026-06-25 ci: Add KiCad CI
2026-07-04 schematic: Rename some nets to match naming scheme
    [rear_distribution.kicad_pcb, rear_distribution.kicad_sch]
2026-07-04 ci: Update to latest KiCad workflow
2026-07-04 schematic: Exclude some test points from the BOM
    [microcontroller.kicad_sch, rear_distribution.kicad_pcb]
2026-08-14 *: Fix shutdown labelling mismatch
    [microcontroller.kicad_sch, rear_distribution.kicad_pcb, rear_distribution.kicad_sch]
